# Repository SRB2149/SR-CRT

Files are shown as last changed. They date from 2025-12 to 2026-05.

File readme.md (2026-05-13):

# CRT HDMI Bridge

Live HDMI video on a vintage monochrome CRT, via a Raspberry Pi, an FPGA and a custom interface PCB.

A desktop PC outputs HDMI to a USB capture card on a Raspberry Pi Zero 2 W. The Pi downscales the feed to 296x256, dithers it to 1 bit per pixel using Atkinson dither, and streams it over SPI to an FPGA. The FPGA then drives the Amstrad GT65 CRT monitor at 50 Hz.

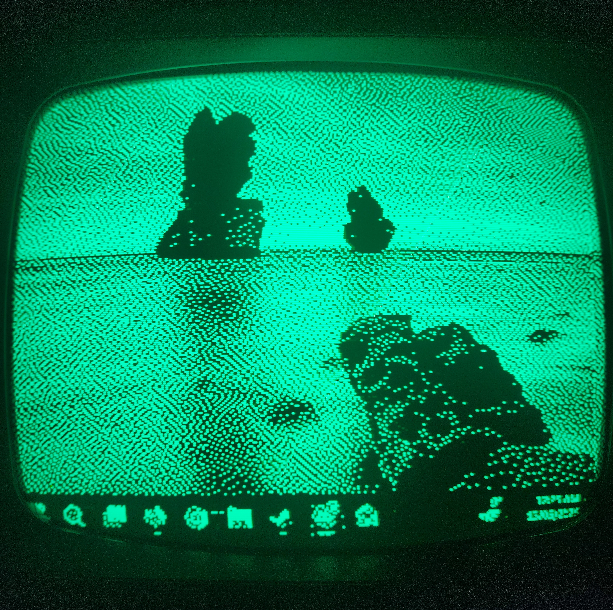
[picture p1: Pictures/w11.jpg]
Photo of a monochrome green CRT showing the windows 11 background.


## Hardware

- Raspberry Pi Zero 2 W
- UVC-compliant HDMI capture card (MS2130-based works well)
- Sipeed Tang Nano 9K (or any small FPGA with LVDS output and at least 16kiB Block SRAM)
- Custom interface PCB (The files are provided if you wish to have it fabricated - or if you would rather I still have some spare which can be bought. Enquire for more info)
- Amstrad GT65 monochrome CRT monitor
- 5V power supply (Or you can use the CRT's own 5V output)

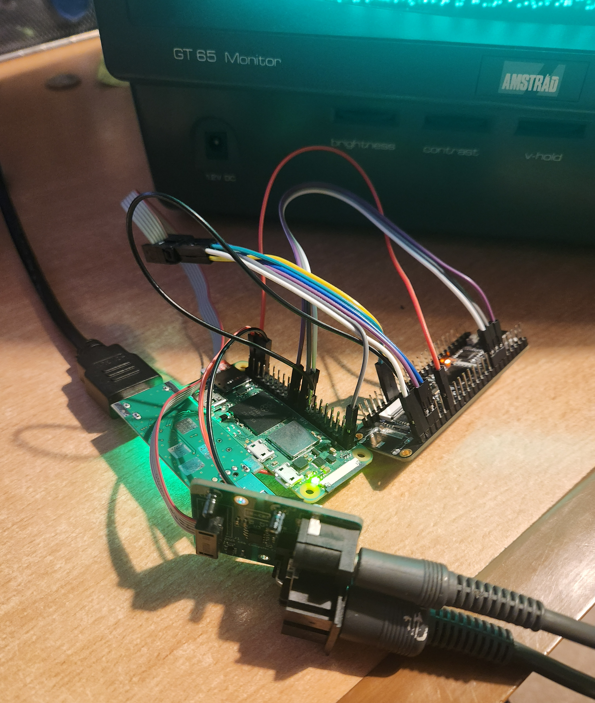
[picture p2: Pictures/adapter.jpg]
Photo of 4 PCBs connected with jumper wires connected to a CRT and a HDMI cable.


## How it works

```
PC --HDMI--> Capture Card --USB--> Pi --SPI--> FPGA --LVDS--> Interface PCB --Serial--> CRT
```

The Pi does the heavy lifting in software (capture, scale, dither). The FPGA does the time-critical CRT signal generation in hardware. SPI between them runs at 50 MHz and carries one 9472-byte framebuffer per CRT frame. The interface PCB acts as a level shifter as well as (depending on the setup) an electrical isolator. 
In theory the CRT could be directly driven using a level shifter from the FPGA, but you are on your own if you wish to attempt that.

In Windows 11 itself the monitor is set to 640x480 at 60 Hz.

The custom interface PCB once assembled
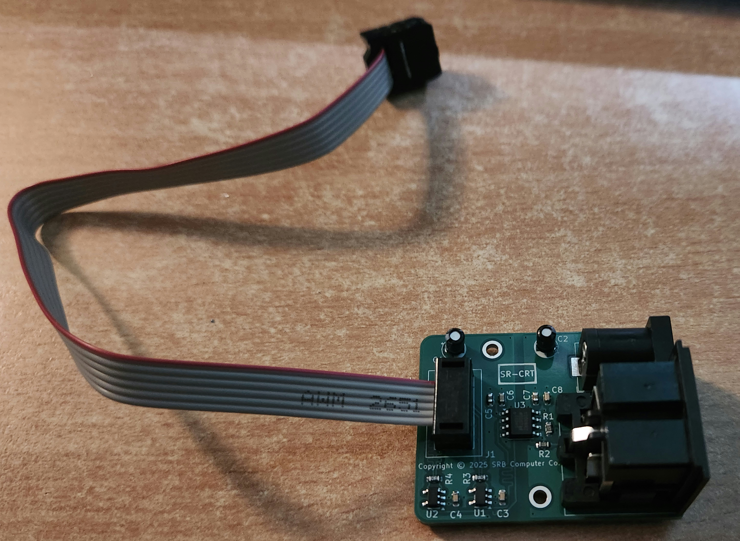
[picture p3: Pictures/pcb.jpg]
Photo of the interface PCB.


Here is the CRT showing the languages section of this repo!
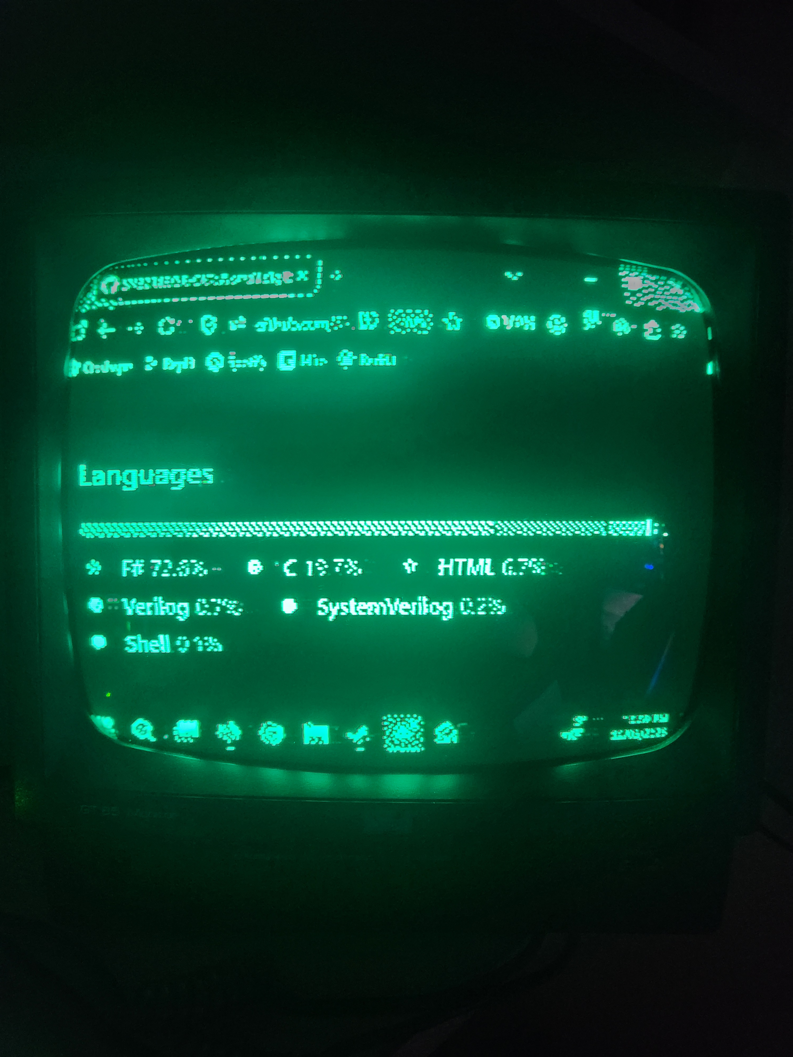
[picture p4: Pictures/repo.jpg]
Photo of the CRT displaying the languages section of this repository.


## Setup

For the Raspberry Pi side, see [INSTALL.txt](RPi/INSTALL.txt). The short version:

1. Flash Raspberry Pi OS Lite (64-bit) with WiFi and SSH preconfigured
2. `scp` the contents of `RPi/` to the Pi
3. Run `./setup_pi.sh` and reboot

For the FPGA side, open the project in your toolchain of choice and flash to your board. Pin assignments are in the top-level constraints file.
You can flash the [SPI_to_CRT.fs](FPGA/SPI_to_CRT/impl/pnr/SPI_to_CRT.fs) binary file directly if you have a GW1NR-LV9C (Tang Nano 9K) FPGA. Otherwise you will need to resynthesise etc.

## Acknowledgements

The Raspberry Pi software was written by Claude (Anthropic) under my supervision. The FPGA work and the rest is mine. For enquiries, contact contact@stanleybooth.uk.

## License

This project is licensed under the MIT License — see [LICENSE](LICENSE) for details.

## Gallery

Here are some more photos of the CRT in action. These photos do not capture the real feeling of the CRT particularly well. It looks much better in real life, especially when displaying videos or things that move as the ghosting leaves a very cool effect. The dithering also provides an incredible amount of information given the limited pixels. It really has to be seen in person to truly appreciate.

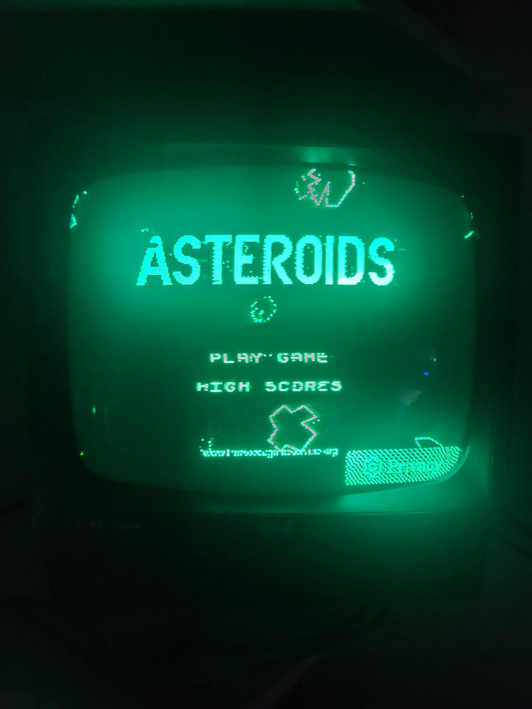
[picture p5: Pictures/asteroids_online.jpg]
Photo of the CRT with the game asteroids on it.

Asteroids online

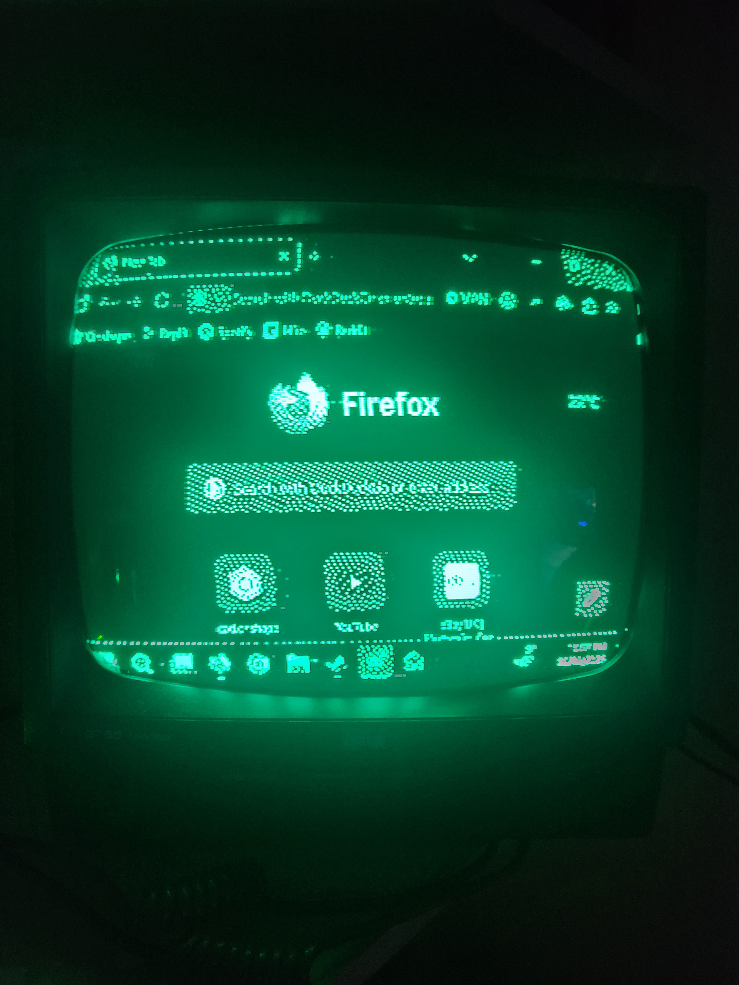
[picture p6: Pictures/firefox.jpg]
Photo of the CRT with a Firefox window open.

Firefox

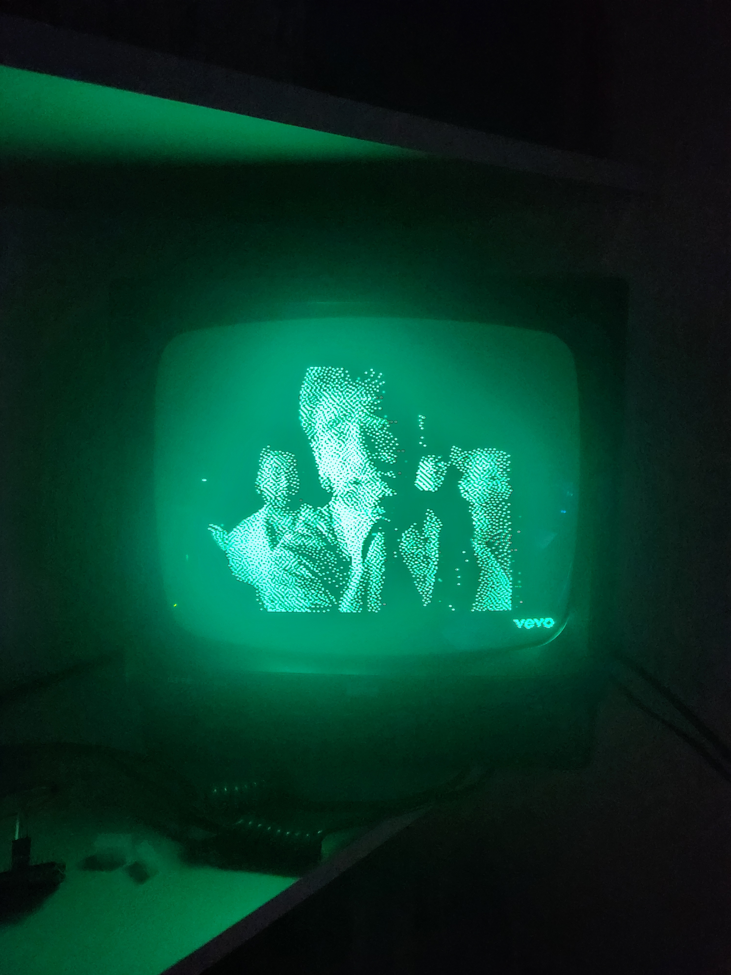
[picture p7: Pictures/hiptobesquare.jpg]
Photo of the CRT with a frame from the song "Hip to Be Square" by Huey Lewis and the News

A frame from the song "Hip to Be Square" by Huey Lewis and the News on youtube.

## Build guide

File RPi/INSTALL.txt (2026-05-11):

CRT HDMI Bridge - Raspberry Pi Setup Guide
==========================================

To preface:
The C code in this folder was written by Claude (Anthropic), not by me. 
Similarly this guide was written by Claude too, however I have read it myself
to check everything seems OK.
If you have any issues feel free to email contact@stanleybooth.uk

What you need
-------------
- Raspberry Pi Zero 2 W (other Pis should work but only the Zero 2 W is tested)
- A good 5V power supply (the official Pi PSU is fine; cheap phone chargers
  often aren't)
- A microSD card, 8GB or larger, ideally a name-brand A1-rated one
- A UVC-compliant HDMI capture card (anything that exposes YUYV at 640x480 over
  V4L2 will work; MS2130-based cards are cheap and good)
- The FPGA board with the matching SPI-to-CRT firmware

Operating system
----------------
Install Raspberry Pi OS Lite (64-bit) using Raspberry Pi Imager. In the
Imager's advanced options (gear icon), set:
  - hostname (something memorable like 'crtpi')
  - username and password
  - WiFi credentials (the Zero 2 W is 2.4 GHz only)
  - WiFi country (set this correctly or WiFi may refuse to associate)
  - enable SSH, ideally with public-key auth

Flash the card, put it in the Pi, power it on, and wait about 2 minutes for
first-boot to complete. Then SSH in from your laptop:

  ssh user@crtpi.local

Setup script
------------
Copy the project files to the Pi:

  scp setup_pi.sh build.sh v4l2_to_spi_atkinson.c user@crtpi.local:~/

SSH in and run the setup script:

  ssh user@crtpi.local
  chmod +x setup_pi.sh build.sh
  ./setup_pi.sh

This will install packages, enable SPI, set the spidev buffer size, configure
groups, build the binary, install the systemd service, and enable the
read-only root overlay. Reboot when it tells you to.

After reboot the program will start automatically and keep running. Power the
Pi by yanking the cable whenever you like - the SD card is mounted read-only
so it won't get corrupted.

Choosing the dither algorithm
-----------------------------
Two C files are provided:
  - v4l2_to_spi.c             - Bayer 8x8 ordered dither (cheap, fast)
  - v4l2_to_spi_atkinson.c    - Atkinson error-diffusion dither (much nicer)

The Atkinson dither looks significantly better in my opinion - it preserves
text and edges far better than Bayer and is what the setup script uses by
default. If you'd rather use Bayer, edit build.sh to point at v4l2_to_spi.c
instead.

Useful commands
---------------
After install:

  sudo systemctl status v4l2-to-spi      # check the program is running
  journalctl -u v4l2-to-spi -f           # watch the output (fps etc.)
  sudo systemctl restart v4l2-to-spi     # restart after changes
  sudo systemctl stop v4l2-to-spi        # stop temporarily

To edit the program you'll need to disable the read-only overlay first:

  sudo raspi-config
  # Performance Options -> Overlay FS -> No
  # Reboot

Then edit, rebuild with ./build.sh, restart the service, and re-enable
overlay when you're done.

Troubleshooting
---------------
"Can't connect to capture card" - run v4l2-ctl --list-devices to confirm
it's plugged in and the kernel sees it.

"SPI errors" - check /sys/module/spidev/parameters/bufsiz is 65536. If not,
the setup script's cmdline.txt edit didn't take effect.

"No image on CRT" - probe MOSI, SCLK, and CS with a logic analyzer. You
should see ~1.5 ms bursts at 60 Hz with CS held low for the duration.

"Under-voltage warnings" - get a better power supply. Check with:
  vcgencmd get_throttled
A return value of 0x0 means everything is fine.

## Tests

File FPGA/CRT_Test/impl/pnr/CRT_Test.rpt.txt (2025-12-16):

//Copyright (C)2014-2024 Gowin Semiconductor Corporation.
//All rights reserved.

1. PnR Messages

  <Report Title>: PnR Report
  <Design File>: C:\Users\stanr\Documents\SR-CRT\FPGA\CRT_Test\impl\gwsynthesis\CRT_Test.vg
  <Physical Constraints File>: C:\Users\stanr\Documents\SR-CRT\FPGA\CRT_Test\src\CRT_Test.cst
  <Timing Constraints File>: ---
  <Tool Version>: V1.9.10.03 Education (64-bit)
  <Part Number>: GW1NR-LV9QN88PC6/I5
  <Device>: GW1NR-9
  <Device Version>: C
  <Created Time>:Mon Dec 15 19:43:51 2025

2. PnR Details

  Running placement:
    Placement Phase 0: CPU time = 0h 0m 0.008s, Elapsed time = 0h 0m 0.008s
    Placement Phase 1: CPU time = 0h 0m 0.068s, Elapsed time = 0h 0m 0.067s
    Placement Phase 2: CPU time = 0h 0m 0.008s, Elapsed time = 0h 0m 0.009s
    Placement Phase 3: CPU time = 0h 0m 0.502s, Elapsed time = 0h 0m 0.503s
    Total Placement: CPU time = 0h 0m 0.586s, Elapsed time = 0h 0m 0.587s
 Running routing:
    Routing Phase 0: CPU time = 0h 0m 0.001s, Elapsed time = 0h 0m 0s
    Routing Phase 1: CPU time = 0h 0m 0.087s, Elapsed time = 0h 0m 0.088s
    Routing Phase 2: CPU time = 0h 0m 0.091s, Elapsed time = 0h 0m 0.091s
    Routing Phase 3: CPU time = 0h 0m 0s, Elapsed time = 0h 0m 0s
    Total Routing: CPU time = 0h 0m 0.179s, Elapsed time = 0h 0m 0.179s
 Generate output files:
    CPU time = 0h 0m 0.737s, Elapsed time = 0h 0m 0.736s

 Total Time and Memory Usage: CPU time = 0h 0m 2s, Elapsed time = 0h 0m 2s, Peak memory usage = 470MB

3. Resource Usage Summary

  --------------------------------------------------------------------------------
  Resources                   | Usage                               | Utilization
  --------------------------------------------------------------------------------
  Logic                       | 151/8640                            |  2%
    --LUT,ALU,ROM16           | 151(151 LUT, 0 ALU, 0 ROM16)        | -
    --SSRAM(RAM16)            | 0                                   | -
  Register                    | 52/6693                             |  <1%
    --Logic Register as Latch | 0/6480                              |  0%
    --Logic Register as FF    | 52/6480                             |  <1%
    --I/O Register as Latch   | 0/213                               |  0%
    --I/O Register as FF      | 0/213                               |  0%
  CLS                         | 86/4320                             |  2%
  I/O Port                    | 7/71                                |  10%
  I/O Buf                     | 5                                   | -
    --Input Buf               | 1                                   | -
    --Output Buf              | 4                                   | -
    --Inout Buf               | 0                                   | -
  BSRAM                       | 5/26                                | 20%
    --DPB                     | 5
  ================================================================================

4. I/O Bank Usage Summary

  --------------------------------------
  I/O Bank  | Usage       | Utilization 
  --------------------------------------
  bank 1   | 2/25        | 8%          
  bank 2   | 4/23        | 18%         
  bank 3   | 1/23        | 5%          
  ======================================

5. Clock Resource Usage Summary

  ------------------------------------------
  Clock Resource| Usage         | Utilization 
  ------------------------------------------
  PRIMARY       | 1/8           | 13%
  LW            | 1/8           | 13%
  GCLK_PIN      | 0/3           | 0%
  OSC           | 1/1           | 100%
  ==========================================

6. Global Clock Signals

  -------------------------------------------
  Signal         | Global Clock   | Location
  -------------------------------------------
  clk            | PRIMARY        |  TL BR BL
  N_RESET_d      | LW             |  -
  ===========================================

7. Pinout by Port Name

------------------------------------------------------------------------------------------------------------------------------------------------------------------------------------------------------------------
Port Name  | Diff Pair | Loc./Bank     | Constraint | Dir.  | Site     | IO Type    | Drive | Pull Mode | PCI Clamp | Hysteresis | Open Drain | Vref       | Single Resistor | Diff Resistor | BankVccio 
------------------------------------------------------------------------------------------------------------------------------------------------------------------------------------------------------------------
N_RESET    | -         | 4/3           | Y          | in    | IOL5[A]  | LVCMOS18   | NA    | UP        | ON        | NONE       | NA         | NA         | OFF             | NA            | 1.8       
PIXEL      | PIXEL_N   | 54,53/1       | Y          | out   | IOR15    | LVDS25     | 2.5   | NONE      | NA        | NA         | NA         | NA         | NA              | NA            | 2.5       
SYNC       | SYNC_N    | 31,32/2       | Y          | out   | IOB15    | LVDS25     | 2.5   | NONE      | NA        | NA         | NA         | NA         | NA              | NA            | 2.5       
pixel      | -         | 38/2          | Y          | out   | IOB31[B] | LVCMOS25   | 8     | UP        | NA        | NA         | OFF        | NA         | NA              | NA            | 2.5       
sync       | -         | 37/2          | Y          | out   | IOB31[A] | LVCMOS25   | 8     | UP        | NA        | NA         | OFF        | NA         | NA              | NA            | 2.5       
==================================================================================================================================================================================================================

8. All Package Pins

-------------------------------------------------------------------------------------------------------------------------------------------------------------------------------------
Loc./Bank| Signal   | Dir.  | Site     | IO Type  | Drive | Pull Mode | PCI Clamp | Hysteresis | Open Drain | Vref       | Single Resistor | Diff Resistor | Bank Vccio
-------------------------------------------------------------------------------------------------------------------------------------------------------------------------------------
3/3      | -        | in    | IOT2[A]  | LVCMOS18 | NA    | UP        | ON        | NONE       | NA         | NA         | NA              | NA            | 1.8  
88/3     | -        | in    | IOT5[A]  | LVCMOS18 | NA    | UP        | ON        | NONE       | NA         | NA         | NA              | NA            | 1.8  
87/3     | -        | in    | IOT6[B]  | LVCMOS18 | NA    | UP        | ON        | NONE       | NA         | NA         | NA              | NA            | 1.8  
86/3     | -        | in    | IOT8[A]  | LVCMOS18 | NA    | UP        | ON        | NONE       | NA         | NA         | NA              | NA            | 1.8  
85/3     | -        | in    | IOT8[B]  | LVCMOS18 | NA    | UP        | ON        | NONE       | NA         | NA         | NA              | NA            | 1.8  
84/3     | -        | in    | IOT10[A] | LVCMOS18 | NA    | UP        | ON        | NONE       | NA         | NA         | NA              | NA            | 1.8  
83/3     | -        | in    | IOT10[B] | LVCMOS18 | NA    | UP        | ON        | NONE       | NA         | NA         | NA              | NA            | 1.8  
82/3     | -        | in    | IOT11[A] | LVCMOS18 | NA    | UP        | ON        | NONE       | NA         | NA         | NA              | NA            | 1.8  
81/3     | -        | in    | IOT11[B] | LVCMOS18 | NA    | UP        | ON        | NONE       | NA         | NA         | NA              | NA            | 1.8  
80/3     | -        | in    | IOT12[A] | LVCMOS18 | NA    | UP        | ON        | NONE       | NA         | NA         | NA              | NA            | 1.8  
79/3     | -        | in    | IOT12[B] | LVCMOS18 | NA    | UP        | ON        | NONE       | NA         | NA         | NA              | NA            | 1.8  
77/1     | -        | in    | IOT37[A] | LVCMOS18 | NA    | UP        | ON        | NONE       | NA         | NA         | NA              | NA            | 2.5  
76/1     | -        | in    | IOT37[B] | LVCMOS18 | NA    | UP        | ON        | NONE       | NA         | NA         | NA              | NA            | 2.5  
75/1     | -        | in    | IOT38[A] | LVCMOS18 | NA    | UP        | ON        | NONE       | NA         | NA         | NA              | NA            | 2.5  
74/1     | -        | in    | IOT38[B] | LVCMOS18 | NA    | UP        | ON        | NONE       | NA         | NA         | NA              | NA            | 2.5  
73/1     | -        | in    | IOT39[A] | LVCMOS18 | NA    | UP        | ON        | NONE       | NA         | NA         | NA              | NA            | 2.5  
72/1     | -        | in    | IOT39[B] | LVCMOS18 | NA    | UP        | ON        | NONE       | NA         | NA         | NA              | NA            | 2.5  
71/1     | -        | in    | IOT41[A] | LVCMOS18 | NA    | UP        | ON        | NONE       | NA         | NA         | NA              | NA            | 2.5  
70/1     | -        | in    | IOT41[B] | LVCMOS18 | NA    | UP        | ON        | NONE       | NA         | NA         | NA              | NA            | 2.5  
69/1     | -        | in    | IOT42[A] | LVCMOS18 | NA    | UP        | ON        | NONE       | NA         | NA         | NA              | NA            | 2.5  
68/1     | -        | in    | IOT42[B] | LVCMOS18 | NA    | UP        | ON        | NONE       | NA         | NA         | NA              | NA            | 2.5  
-------------------------------------------------------------------------------------------------------------------------------------------------------------------------------------
17/2     | -        | in    | IOB2[A]  | LVCMOS18 | NA    | UP        | ON        | NONE       | NA         | NA         | NA              | NA            | 2.5  
18/2     | -        | in    | IOB2[B]  | LVCMOS18 | NA    | UP        | ON        | NONE       | NA         | NA         | NA              | NA            | 2.5  
19/2     | -        | in    | IOB4[A]  | LVCMOS18 | NA    | UP        | ON        | NONE       | NA         | NA         | NA              | NA            | 2.5  
20/2     | -        | in    | IOB4[B]  | LVCMOS18 | NA    | UP        | ON        | NONE       | NA         | NA         | NA              | NA            | 2.5  
25/2     | -        | in    | IOB8[A]  | LVCMOS18 | NA    | UP        | ON        | NONE       | NA         | NA         | NA              | NA            | 2.5  
26/2     | -        | in    | IOB8[B]  | LVCMOS18 | NA    | UP        | ON        | NONE       | NA         | NA         | NA              | NA            | 2.5  
27/2     | -        | in    | IOB11[A] | LVCMOS18 | NA    | UP        | ON        | NONE       | NA         | NA         | NA              | NA            | 2.5  
28/2     | -        | in    | IOB11[B] | LVCMOS18 | NA    | UP        | ON        | NONE       | NA         | NA         | NA              | NA            | 2.5  
29/2     | -        | in    | IOB13[A] | LVCMOS18 | NA    | UP        | ON        | NONE       | NA         | NA         | NA              | NA            | 2.5  
30/2     | -        | in    | IOB13[B] | LVCMOS18 | NA    | UP        | ON        | NONE       | NA         | NA         | NA              | NA            | 2.5  
31/2     | SYNC     | out   | IOB15[A] | LVDS25   | 2.5   | NONE      | NA        | NA         | NA         | NA         | NA              | NA            | 2.5  
32/2     | SYNC_N   | out   | IOB15[B] | LVDS25   | 2.5   | NONE      | NA        | NA         | NA         | NA         | NA              | NA            | 2.5  
33/2     | -        | in    | IOB23[A] | LVCMOS18 | NA    | UP        | ON        | NONE       | NA         | NA         | NA              | NA            | 2.5  
34/2     | -        | in    | IOB23[B] | LVCMOS18 | NA    | UP        | ON        | NONE       | NA         | NA         | NA              | NA            | 2.5  
35/2     | -        | in    | IOB29[A] | LVCMOS18 | NA    | UP        | ON        | NONE       | NA         | NA         | NA              | NA            | 2.5  
36/2     | -        | in    | IOB29[B] | LVCMOS18 | NA    | UP        | ON        | NONE       | NA         | NA         | NA              | NA            | 2.5  
37/2     | sync     | out   | IOB31[A] | LVCMOS25 | 8     | UP        | NA        | NA         | OFF        | NA         | NA              | NA            | 2.5  
38/2     | pixel    | out   | IOB31[B] | LVCMOS25 | 8     | UP        | NA        | NA         | OFF        | NA         | NA              | NA            | 2.5  
39/2     | -        | in    | IOB33[A] | LVCMOS18 | NA    | UP        | ON        | NONE       | NA         | NA         | NA              | NA            | 2.5  
40/2     | -        | in    | IOB33[B] | LVCMOS18 | NA    | UP        | ON        | NONE       | NA         | NA         | NA              | NA            | 2.5  
41/2     | -        | in    | IOB41[A] | LVCMOS18 | NA    | UP        | ON        | NONE       | NA         | NA         | NA              | NA            | 2.5  
42/2     | -        | in    | IOB41[B] | LVCMOS18 | NA    | UP        | ON        | NONE       | NA         | NA         | NA              | NA            | 2.5  
47/2     | -        | in    | IOB43[B] | LVCMOS18 | NA    | UP        | ON        | NONE       | NA         | NA         | NA              | NA            | 2.5  
-------------------------------------------------------------------------------------------------------------------------------------------------------------------------------------
4/3      | N_RESET  | in    | IOL5[A]  | LVCMOS18 | NA    | UP        | ON        | NONE       | NA         | NA         | OFF             | NA            | 1.8  
5/3      | -        | in    | IOL11[A] | LVCMOS18 | NA    | UP        | ON        | NONE       | NA         | NA         | NA              | NA            | 1.8  
6/3      | -        | in    | IOL11[B] | LVCMOS18 | NA    | UP        | ON        | NONE       | NA         | NA         | NA              | NA            | 1.8  
7/3      | -        | in    | IOL12[B] | LVCMOS18 | NA    | UP        | ON        | NONE       | NA         | NA         | NA              | NA            | 1.8  
8/3      | -        | out   | IOL13[A] | LVCMOS18 | 8     | UP        | NA        | NA         | OFF        | NA         | NA              | NA            | 1.8  
9/3      | -        | in    | IOL13[B] | LVCMOS18 | NA    | UP        | ON        | NONE       | NA         | NA         | NA              | NA            | 1.8  
10/3     | -        | in    | IOL15[A] | LVCMOS18 | NA    | UP        | ON        | NONE       | NA         | NA         | NA              | NA            | 1.8  
11/3     | -        | in    | IOL16[B] | LVCMOS18 | NA    | UP        | ON        | NONE       | NA         | NA         | NA              | NA            | 1.8  
13/3     | -        | in    | IOL21[B] | LVCMOS18 | NA    | UP        | ON        | NONE       | NA         | NA         | NA              | NA            | 1.8  
14/3     | -        | in    | IOL22[B] | LVCMOS18 | NA    | UP        | ON        | NONE       | NA         | NA         | NA              | NA            | 1.8  
15/3     | -        | in    | IOL25[B] | LVCMOS18 | NA    | UP        | ON        | NONE       | NA         | NA         | NA              | NA            | 1.8  
16/3     | -        | in    | IOL26[B] | LVCMOS18 | NA    | UP        | ON        | NONE       | NA         | NA         | NA              | NA            | 1.8  
-------------------------------------------------------------------------------------------------------------------------------------------------------------------------------------
63/1     | -        | in    | IOR5[A]  | LVCMOS18 | NA    | UP        | ON        | NONE       | NA         | NA         | NA              | NA            | 2.5  
62/1     | -        | in    | IOR11[A] | LVCMOS18 | NA    | UP        | ON        | NONE       | NA         | NA         | NA              | NA            | 2.5  
61/1     | -        | in    | IOR11[B] | LVCMOS18 | NA    | UP        | ON        | NONE       | NA         | NA         | NA              | NA            | 2.5  
60/1     | -        | in    | IOR12[A] | LVCMOS18 | NA    | UP        | ON        | NONE       | NA         | NA         | NA              | NA            | 2.5  
59/1     | -        | in    | IOR12[B] | LVCMOS18 | NA    | UP        | ON        | NONE       | NA         | NA         | NA              | NA            | 2.5  
57/1     | -        | in    | IOR13[A] | LVCMOS18 | NA    | UP        | ON        | NONE       | NA         | NA         | NA              | NA            | 2.5  
56/1     | -        | in    | IOR14[A] | LVCMOS18 | NA    | UP        | ON        | NONE       | NA         | NA         | NA              | NA            | 2.5  
55/1     | -        | in    | IOR14[B] | LVCMOS18 | NA    | UP        | ON        | NONE       | NA         | NA         | NA              | NA            | 2.5  
54/1     | PIXEL    | out   | IOR15[A] | LVDS25   | 2.5   | NONE      | NA        | NA         | NA         | NA         | NA              | NA            | 2.5  
53/1     | PIXEL_N  | out   | IOR15[B] | LVDS25   | 2.5   | NONE      | NA        | NA         | NA         | NA         | NA              | NA            | 2.5  
52/1     | -        | in    | IOR17[A] | LVCMOS18 | NA    | UP        | ON        | NONE       | NA         | NA         | NA              | NA            | 2.5  
51/1     | -        | in    | IOR17[B] | LVCMOS18 | NA    | UP        | ON        | NONE       | NA         | NA         | NA              | NA            | 2.5  
50/1     | -        | in    | IOR22[B] | LVCMOS18 | NA    | UP        | ON        | NONE       | NA         | NA         | NA              | NA            | 2.5  
49/1     | -        | in    | IOR24[A] | LVCMOS18 | NA    | UP        | ON        | NONE       | NA         | NA         | NA              | NA            | 2.5  
48/1     | -        | in    | IOR24[B] | LVCMOS18 | NA    | UP        | ON        | NONE       | NA         | NA         | NA              | NA            | 2.5  
-------------------------------------------------------------------------------------------------------------------------------------------------------------------------------------
=====================================================================================================================================================================================

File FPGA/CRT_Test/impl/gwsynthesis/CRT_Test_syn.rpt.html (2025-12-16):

- Synthesis Messages
- Synthesis Details
- Resource
  - Resource Usage Summary
  - Resource Utilization Summary
- Timing
  - Clock Summary
  - Max Frequency Summary
  - Detail Timing Paths Informations

# Synthesis Messages

Report Title | GowinSynthesis Report
Design File | C:\Users\stanr\Documents\SR-CRT\FPGA\Controller\amstrad_gt65_crt_controller.sv C:\Users\stanr\Documents\SR-CRT\FPGA\test.sv C:\Users\stanr\Documents\SR-CRT\FPGA\CRT_Test\src\gowin_osc\gowin_osc.v C:\Users\stanr\Documents\SR-CRT\FPGA\CRT_Test\src\gowin_dpb\crt_frame_buffer_dpbsram.v
GowinSynthesis Constraints File | ---
Tool Version | V1.9.10.03 Education (64-bit)
Part Number | GW1NR-LV9QN88PC6/I5
Device | GW1NR-9
Device Version | C
Created Time | Mon Dec 15 19:43:49 2025
Legal Announcement | Copyright (C)2014-2024 Gowin Semiconductor Corporation. ALL rights reserved.

# Synthesis Details

Top Level Module | CRT_Test

Synthesis Process

Running parser:
CPU time = 0h 0m 0.078s, Elapsed time = 0h 0m 0.075s, Peak memory usage = 470.621MB
Running netlist conversion:
CPU time = 0h 0m 0s, Elapsed time = 0h 0m 0s, Peak memory usage = 0MB
Running device independent optimization:
Optimizing Phase 0: CPU time = 0h 0m 0.015s, Elapsed time = 0h 0m 0.004s, Peak memory usage = 470.621MB
Optimizing Phase 1: CPU time = 0h 0m 0s, Elapsed time = 0h 0m 0.006s, Peak memory usage = 470.621MB
Optimizing Phase 2: CPU time = 0h 0m 0s, Elapsed time = 0h 0m 0.007s, Peak memory usage = 470.621MB
Running inference:
Inferring Phase 0: CPU time = 0h 0m 0.015s, Elapsed time = 0h 0m 0s, Peak memory usage = 470.621MB
Inferring Phase 1: CPU time = 0h 0m 0s, Elapsed time = 0h 0m 0s, Peak memory usage = 470.621MB
Inferring Phase 2: CPU time = 0h 0m 0s, Elapsed time = 0h 0m 0s, Peak memory usage = 470.621MB
Inferring Phase 3: CPU time = 0h 0m 0s, Elapsed time = 0h 0m 0s, Peak memory usage = 470.621MB
Running technical mapping:
Tech-Mapping Phase 0: CPU time = 0h 0m 0s, Elapsed time = 0h 0m 0.004s, Peak memory usage = 470.621MB
Tech-Mapping Phase 1: CPU time = 0h 0m 0s, Elapsed time = 0h 0m 0.001s, Peak memory usage = 470.621MB
Tech-Mapping Phase 2: CPU time = 0h 0m 0s, Elapsed time = 0h 0m 0s, Peak memory usage = 470.621MB
Tech-Mapping Phase 3: CPU time = 0h 0m 0.39s, Elapsed time = 0h 0m 0.393s, Peak memory usage = 470.621MB
Tech-Mapping Phase 4: CPU time = 0h 0m 0.015s, Elapsed time = 0h 0m 0.015s, Peak memory usage = 470.621MB
Generate output files:
CPU time = 0h 0m 0.015s, Elapsed time = 0h 0m 0.013s, Peak memory usage = 470.621MB
Total Time and Memory Usage | CPU time = 0h 0m 0.528s, Elapsed time = 0h 0m 0.518s, Peak memory usage = 470.621MB

# Resource

## Resource Usage Summary

Resource | Usage
I/O Port | 7
I/O Buf | 5
IBUF | 1
OBUF | 2
TLVDS_OBUF | 2
Register | 52
DFFE | 1
DFFPE | 1
DFFC | 14
DFFCE | 36
LUT | 134
LUT2 | 15
LUT3 | 36
LUT4 | 83
MUX | 8
MUX2 | 8
INV | 6
INV | 6
BSRAM | 5
DPB | 5
CLOCK | 1
OSC | 1

## Resource Utilization Summary

Resource | Usage | Utilization
Logic | 148(148 LUT, 0 ALU) / 8640 | 2%
Register | 52 / 6693 | <1%
--Register as Latch | 0 / 6693 | 0%
--Register as FF | 52 / 6693 | <1%
BSRAM | 5 / 26 | 20%

# Timing

## Clock Summary:

NO. | Clock Name | Type | Period | Frequency(MHz) | Rise | Fall | Source | Master | Object
1 | internal_clk0/osc_inst/OSCOUT.default_clk | Base | 16.000 | 62.5 | 0.000 | 8.000 | | | internal_clk0/osc_inst/OSCOUT

## Max Frequency Summary:

NO. | Clock Name | Constraint | Actual Fmax | Logic Level | Entity
1 | internal_clk0/osc_inst/OSCOUT.default_clk | 62.500(MHz) | 99.460(MHz) | 5 | TOP

## Detail Timing Paths Information

### Path 1

Path Summary:

Slack | 5.946
Data Arrival Time | 10.380
Data Required Time | 16.326
From | crt0/horizontal_counter_9_s0
To | crt0/vsync_s1
Launch Clk | internal_clk0/osc_inst/OSCOUT.default_clk[R]
Latch Clk | internal_clk0/osc_inst/OSCOUT.default_clk[R]

Data Arrival Path:

AT | DELAY | TYPE | RF | FANOUT | NODE
0.000 | 0.000 | | | | internal_clk0/osc_inst/OSCOUT.default_clk
0.000 | 0.000 | tCL | RR | 57 | internal_clk0/osc_inst/OSCOUT
0.726 | 0.726 | tNET | RR | 1 | crt0/horizontal_counter_9_s0/CLK
1.184 | 0.458 | tC2Q | RF | 9 | crt0/horizontal_counter_9_s0/Q
2.144 | 0.960 | tNET | FF | 1 | crt0/n384_s26/I1
3.243 | 1.099 | tINS | FF | 1 | crt0/n384_s26/F
4.203 | 0.960 | tNET | FF | 1 | crt0/n384_s20/I1
5.302 | 1.099 | tINS | FF | 1 | crt0/n384_s20/F
6.262 | 0.960 | tNET | FF | 1 | crt0/n384_s14/I1
7.361 | 1.099 | tINS | FF | 1 | crt0/n384_s14/F
8.321 | 0.960 | tNET | FF | 1 | crt0/n384_s12/I1
9.420 | 1.099 | tINS | FF | 1 | crt0/n384_s12/F
10.380 | 0.960 | tNET | FF | 1 | crt0/vsync_s1/D

Data Required Path:

AT | DELAY | TYPE | RF | FANOUT | NODE
16.000 | 0.000 | | | | internal_clk0/osc_inst/OSCOUT.default_clk
16.000 | 0.000 | tCL | RR | 57 | internal_clk0/osc_inst/OSCOUT
16.726 | 0.726 | tNET | RR | 1 | crt0/vsync_s1/CLK
16.326 | -0.400 | tSu | | 1 | crt0/vsync_s1

Path Statistics:

Clock Skew: | 0.000
Setup Relationship: | 16.000
Logic Level: | 5
Arrival Clock Path Delay: | cell: 0.000, 0.000%; route: 0.726, 100.000%
Arrival Data Path Delay: | cell: 4.396, 45.534%; route: 4.800, 49.719%; tC2Q: 0.458, 4.747%
Required Clock Path Delay: | cell: 0.000, 0.000%; route: 0.726, 100.000%

### Path 2

Path Summary:

Slack | 6.013
Data Arrival Time | 10.313
Data Required Time | 16.326
From | crt0/vertical_counter_4_s0
To | crt0/vertical_state_e_1_s6
Launch Clk | internal_clk0/osc_inst/OSCOUT.default_clk[R]
Latch Clk | internal_clk0/osc_inst/OSCOUT.default_clk[R]

Data Arrival Path:

AT | DELAY | TYPE | RF | FANOUT | NODE
0.000 | 0.000 | | | | internal_clk0/osc_inst/OSCOUT.default_clk
0.000 | 0.000 | tCL | RR | 57 | internal_clk0/osc_inst/OSCOUT
0.726 | 0.726 | tNET | RR | 1 | crt0/vertical_counter_4_s0/CLK
1.184 | 0.458 | tC2Q | RF | 9 | crt0/vertical_counter_4_s0/Q
2.144 | 0.960 | tNET | FF | 1 | crt0/vertical_state_e_2_s15/I1
3.243 | 1.099 | tINS | FF | 1 | crt0/vertical_state_e_2_s15/F
4.203 | 0.960 | tNET | FF | 1 | crt0/vertical_state_e_2_s11/I1
5.302 | 1.099 | tINS | FF | 2 | crt0/vertical_state_e_2_s11/F
6.262 | 0.960 | tNET | FF | 1 | crt0/n381_s26/I1
7.361 | 1.099 | tINS | FF | 1 | crt0/n381_s26/F
8.321 | 0.960 | tNET | FF | 1 | crt0/n381_s25/I0
9.353 | 1.032 | tINS | FF | 1 | crt0/n381_s25/F
10.313 | 0.960 | tNET | FF | 1 | crt0/vertical_state_e_1_s6/D

Data Required Path:

AT | DELAY | TYPE | RF | FANOUT | NODE
16.000 | 0.000 | | | | internal_clk0/osc_inst/OSCOUT.default_clk
16.000 | 0.000 | tCL | RR | 57 | internal_clk0/osc_inst/OSCOUT
16.726 | 0.726 | tNET | RR | 1 | crt0/vertical_state_e_1_s6/CLK
16.326 | -0.400 | tSu | | 1 | crt0/vertical_state_e_1_s6

Path Statistics:

Clock Skew: | 0.000
Setup Relationship: | 16.000
Logic Level: | 5
Arrival Clock Path Delay: | cell: 0.000, 0.000%; route: 0.726, 100.000%
Arrival Data Path Delay: | cell: 4.329, 45.153%; route: 4.800, 50.066%; tC2Q: 0.458, 4.781%
Required Clock Path Delay: | cell: 0.000, 0.000%; route: 0.726, 100.000%

### Path 3

Path Summary:

Slack | 6.223
Data Arrival Time | 10.103
Data Required Time | 16.326
From | crt0/vertical_counter_7_s0
To | crt0/vertical_state_e_0_s2
Launch Clk | internal_clk0/osc_inst/OSCOUT.default_clk[R]
Latch Clk | internal_clk0/osc_inst/OSCOUT.default_clk[R]

Data Arrival Path:

AT | DELAY | TYPE | RF | FANOUT | NODE
0.000 | 0.000 | | | | internal_clk0/osc_inst/OSCOUT.default_clk
0.000 | 0.000 | tCL | RR | 57 | internal_clk0/osc_inst/OSCOUT
0.726 | 0.726 | tNET | RR | 1 | crt0/vertical_counter_7_s0/CLK
1.184 | 0.458 | tC2Q | RF | 6 | crt0/vertical_counter_7_s0/Q
2.144 | 0.960 | tNET | FF | 1 | crt0/vertical_state_e_2_s13/I1
3.243 | 1.099 | tINS | FF | 3 | crt0/vertical_state_e_2_s13/F
4.203 | 0.960 | tNET | FF | 1 | crt0/vertical_state_e_2_s9/I2
5.025 | 0.822 | tINS | FF | 3 | crt0/vertical_state_e_2_s9/F
5.985 | 0.960 | tNET | FF | 1 | crt0/n382_s25/I1
7.084 | 1.099 | tINS | FF | 1 | crt0/n382_s25/F
8.044 | 0.960 | tNET | FF | 1 | crt0/n382_s24/I1
9.143 | 1.099 | tINS | FF | 1 | crt0/n382_s24/F
10.103 | 0.960 | tNET | FF | 1 | crt0/vertical_state_e_0_s2/D

Data Required Path:

AT | DELAY | TYPE | RF | FANOUT | NODE
16.000 | 0.000 | | | | internal_clk0/osc_inst/OSCOUT.default_clk
16.000 | 0.000 | tCL | RR | 57 | internal_clk0/osc_inst/OSCOUT
16.726 | 0.726 | tNET | RR | 1 | crt0/vertical_state_e_0_s2/CLK
16.326 | -0.400 | tSu | | 1 | crt0/vertical_state_e_0_s2

Path Statistics:

Clock Skew: | 0.000
Setup Relationship: | 16.000
Logic Level: | 5
Arrival Clock Path Delay: | cell: 0.000, 0.000%; route: 0.726, 100.000%
Arrival Data Path Delay: | cell: 4.119, 43.925%; route: 4.800, 51.187%; tC2Q: 0.458, 4.888%
Required Clock Path Delay: | cell: 0.000, 0.000%; route: 0.726, 100.000%

### Path 4

Path Summary:

Slack | 6.486
Data Arrival Time | 9.840
Data Required Time | 16.326
From | crt0/horizontal_counter_8_s0
To | crt0/horizontal_state_e_0_s2
Launch Clk | internal_clk0/osc_inst/OSCOUT.default_clk[R]
Latch Clk | internal_clk0/osc_inst/OSCOUT.default_clk[R]

Data Arrival Path:

AT | DELAY | TYPE | RF | FANOUT | NODE
0.000 | 0.000 | | | | internal_clk0/osc_inst/OSCOUT.default_clk
0.000 | 0.000 | tCL | RR | 57 | internal_clk0/osc_inst/OSCOUT
0.726 | 0.726 | tNET | RR | 1 | crt0/horizontal_counter_8_s0/CLK
1.184 | 0.458 | tC2Q | RF | 8 | crt0/horizontal_counter_8_s0/Q
2.144 | 0.960 | tNET | FF | 1 | crt0/horizontal_state_e_0_s8/I1
3.243 | 1.099 | tINS | FF | 1 | crt0/horizontal_state_e_0_s8/F
4.203 | 0.960 | tNET | FF | 1 | crt0/horizontal_state_e_0_s7/I0
5.235 | 1.032 | tINS | FF | 1 | crt0/horizontal_state_e_0_s7/F
6.195 | 0.960 | tNET | FF | 1 | crt0/horizontal_state_e_0_s5/I3
6.821 | 0.626 | tINS | FF | 3 | crt0/horizontal_state_e_0_s5/F
7.781 | 0.960 | tNET | FF | 1 | crt0/n585_s28/I1
8.880 | 1.099 | tINS | FF | 1 | crt0/n585_s28/F
9.840 | 0.960 | tNET | FF | 1 | crt0/horizontal_state_e_0_s2/D

Data Required Path:

AT | DELAY | TYPE | RF | FANOUT | NODE
16.000 | 0.000 | | | | internal_clk0/osc_inst/OSCOUT.default_clk
16.000 | 0.000 | tCL | RR | 57 | internal_clk0/osc_inst/OSCOUT
16.726 | 0.726 | tNET | RR | 1 | crt0/horizontal_state_e_0_s2/CLK
16.326 | -0.400 | tSu | | 1 | crt0/horizontal_state_e_0_s2

Path Statistics:

Clock Skew: | 0.000
Setup Relationship: | 16.000
Logic Level: | 5
Arrival Clock Path Delay: | cell: 0.000, 0.000%; route: 0.726, 100.000%
Arrival Data Path Delay: | cell: 3.856, 42.307%; route: 4.800, 52.664%; tC2Q: 0.458, 5.029%
Required Clock Path Delay: | cell: 0.000, 0.000%; route: 0.726, 100.000%

### Path 5

Path Summary:

Slack | 6.500
Data Arrival Time | 9.826
Data Required Time | 16.326
From | crt0/pixel_word_index_1_s0
To | crt0/pixel_word_index_11_s0
Launch Clk | internal_clk0/osc_inst/OSCOUT.default_clk[R]
Latch Clk | internal_clk0/osc_inst/OSCOUT.default_clk[R]

Data Arrival Path:

AT | DELAY | TYPE | RF | FANOUT | NODE
0.000 | 0.000 | | | | internal_clk0/osc_inst/OSCOUT.default_clk
0.000 | 0.000 | tCL | RR | 57 | internal_clk0/osc_inst/OSCOUT
0.726 | 0.726 | tNET | RR | 1 | crt0/pixel_word_index_1_s0/CLK
1.184 | 0.458 | tC2Q | RF | 9 | crt0/pixel_word_index_1_s0/Q
2.144 | 0.960 | tNET | FF | 1 | crt0/n722_s3/I1
3.243 | 1.099 | tINS | FF | 5 | crt0/n722_s3/F
4.203 | 0.960 | tNET | FF | 1 | crt0/n718_s4/I2
5.025 | 0.822 | tINS | FF | 5 | crt0/n718_s4/F
5.985 | 0.960 | tNET | FF | 1 | crt0/n715_s3/I2
6.807 | 0.822 | tINS | FF | 2 | crt0/n715_s3/F
7.767 | 0.960 | tNET | FF | 1 | crt0/n715_s2/I1
8.866 | 1.099 | tINS | FF | 1 | crt0/n715_s2/F
9.826 | 0.960 | tNET | FF | 1 | crt0/pixel_word_index_11_s0/D

Data Required Path:

AT | DELAY | TYPE | RF | FANOUT | NODE
16.000 | 0.000 | | | | internal_clk0/osc_inst/OSCOUT.default_clk
16.000 | 0.000 | tCL | RR | 57 | internal_clk0/osc_inst/OSCOUT
16.726 | 0.726 | tNET | RR | 1 | crt0/pixel_word_index_11_s0/CLK
16.326 | -0.400 | tSu | | 1 | crt0/pixel_word_index_11_s0

Path Statistics:

Clock Skew: | 0.000
Setup Relationship: | 16.000
Logic Level: | 5
Arrival Clock Path Delay: | cell: 0.000, 0.000%; route: 0.726, 100.000%
Arrival Data Path Delay: | cell: 3.842, 42.218%; route: 4.800, 52.746%; tC2Q: 0.458, 5.036%
Required Clock Path Delay: | cell: 0.000, 0.000%; route: 0.726, 100.000%

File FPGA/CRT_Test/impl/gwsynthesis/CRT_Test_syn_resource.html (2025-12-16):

# Hierarchy Module Resource

MODULE NAME | REG NUMBER | ALU NUMBER | LUT NUMBER | DSP NUMBER | BSRAM NUMBER | SSRAM NUMBER | ROM16 NUMBER
CRT_Test (C:/Users/stanr/Documents/SR-CRT/FPGA/test.sv) | - | - | 1 | - | - | - | -
|--crt0 (C:/Users/stanr/Documents/SR-CRT/FPGA/test.sv) | 51 | - | 139 | - | - | - | -
|--internal_clk0 (C:/Users/stanr/Documents/SR-CRT/FPGA/test.sv) | - | - | - | - | - | - | -
|--f_buf0 (C:/Users/stanr/Documents/SR-CRT/FPGA/test.sv) | 1 | - | 8 | - | 5 | - | -

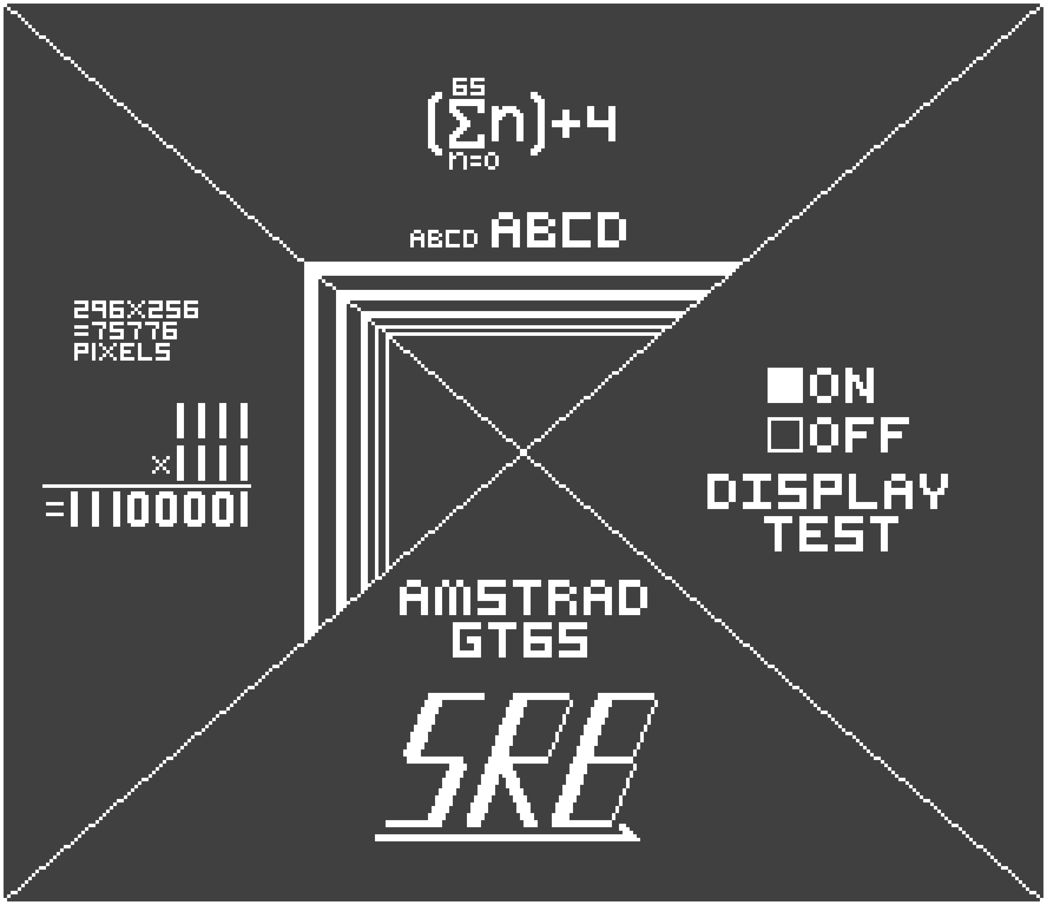
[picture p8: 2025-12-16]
FPGA/TestImages/GT65_296x256_Test.png

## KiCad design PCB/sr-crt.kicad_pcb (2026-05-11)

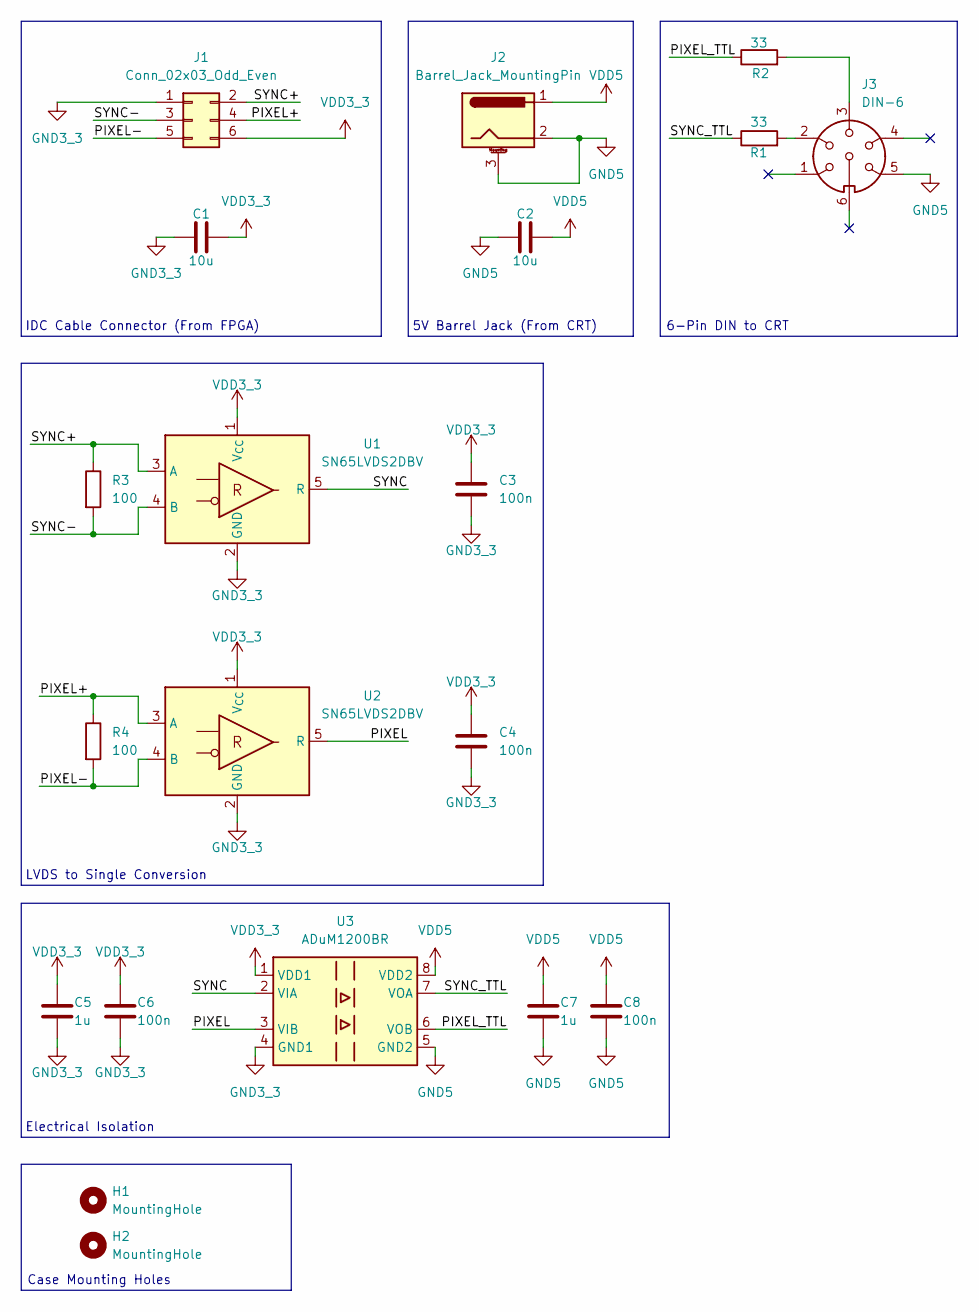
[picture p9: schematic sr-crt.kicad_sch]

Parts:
C1, C2: 10u; CP_Radial_D4.0mm_P2.00mm
C3, C4, C6, C8: 100n; C_0603_1608Metric
C5, C7: 1u; C_0603_1608Metric
H1, H2: MountingHole; MountingHole_2.2mm_M2_ISO7380_Pad_TopBottom
J1: Conn_02x03_Odd_Even; IDC-Header_2x03_P2.54mm_Vertical
J2: Barrel_Jack_MountingPin; BarrelJack_Horizontal
J3: DIN-6; 6_PIN_DIN
R1, R2: 33; R_0603_1608Metric
R3, R4: 100; R_0603_1608Metric
U1, U2: SN65LVDS2DBV; SOT-23-5
U3: ADuM1200BR; SOIC-8_3.9x4.9mm_P1.27mm

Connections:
/PIXEL: U2.5 (R), U3.3 (VIB)
/PIXEL+: J1.4, R4.1, U2.3 (A)
/PIXEL-: J1.5, R4.2, U2.4 (B)
/PIXEL_TTL: R2.1, U3.6 (VOB)
/SYNC: U1.5 (R), U3.2 (VIA)
/SYNC+: J1.2, R3.1, U1.3 (A)
/SYNC-: J1.3, R3.2, U1.4 (B)
/SYNC_TTL: R1.1, U3.7 (VOA)
GND3_3: C1.1, C3.2, C4.2, C5.2, C6.2, J1.1, U1.2 (GND), U2.2 (GND), U3.4 (GND1)
GND5: C2.1, C7.2, C8.2, J2.2, J2.3 (MountPin), J3.5, U3.5 (GND2)
unnamed: J3.2, R1.2
unnamed: J3.3, R2.2
VDD3_3: C1.2, C3.1, C4.1, C5.1, C6.1, J1.6, U1.1 (V_{CC}), U2.1 (V_{CC}), U3.1 (VDD1)
VDD5: C2.2, C7.1, C8.1, J2.1, U3.8 (VDD2)

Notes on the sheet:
6-Pin DIN to CRT
IDC Cable Connector (From FPGA)
5V Barrel Jack (From CRT)
LVDS to Single Conversion
Case Mounting Holes
Electrical Isolation

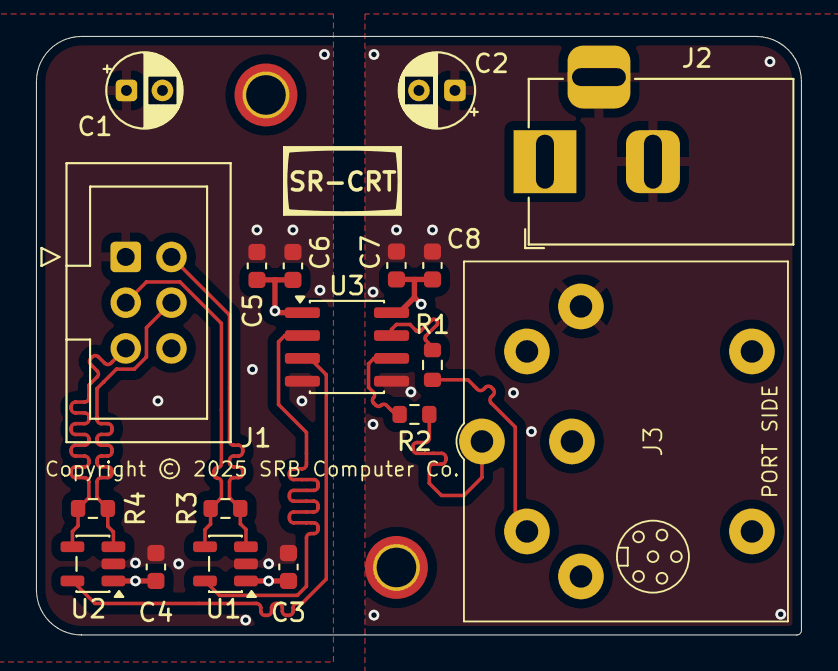
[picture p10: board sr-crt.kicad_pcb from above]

Board: 4 copper layers, 42.5 x 33.2 mm, 20 parts (0 on the bottom side), 14 nets.

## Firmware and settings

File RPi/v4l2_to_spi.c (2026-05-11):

/*
 * v4l2_to_spi.c — capture from a UVC HDMI capture card, downscale to
 * 320x240, dither to 1bpp, and stream to an FPGA over SPI.
 *
 * Designed for a Raspberry Pi Zero 2 W. Assumes the capture card can
 * deliver YUY2 (preferred) or MJPEG. This skeleton handles YUY2 directly;
 * MJPEG requires adding a decode step (see notes at bottom).
 *
 * Build:
 *   gcc -O3 -march=armv8-a -mtune=cortex-a53 -o v4l2_to_spi v4l2_to_spi.c
 *
 * Run (as root or with appropriate permissions on /dev/video0 and /dev/spidev0.0):
 *   ./v4l2_to_spi
 */

#include <errno.h>
#include <fcntl.h>
#include <stdint.h>
#include <stdio.h>
#include <stdlib.h>
#include <string.h>
#include <sys/ioctl.h>
#include <sys/mman.h>
#include <sys/time.h>
#include <unistd.h>
#include <linux/videodev2.h>
#include <linux/spi/spidev.h>

/* ------------------------------------------------------------------ */
/* Configuration                                                       */
/* ------------------------------------------------------------------ */

#define VIDEO_DEV    "/dev/video0"
#define SPI_DEV      "/dev/spidev0.0"

#define CAP_WIDTH    640
#define CAP_HEIGHT   480
#define OUT_WIDTH    296
#define OUT_HEIGHT   256
#define OUT_BYTES    (OUT_WIDTH * OUT_HEIGHT / 8)   /* 9472 bytes, 1bpp */

#define SPI_SPEED_HZ 50000000   /* 50 MHz — drop to 25 MHz if unstable */
#define SPI_BITS     8
#define SPI_MODE     SPI_MODE_0

#define NUM_BUFFERS  4

/* ------------------------------------------------------------------ */
/* Globals                                                             */
/* ------------------------------------------------------------------ */

struct buffer {
    void   *start;
    size_t  length;
};

static int             video_fd = -1;
static int             spi_fd   = -1;
static struct buffer   buffers[NUM_BUFFERS];
static uint8_t         gray_frame[CAP_WIDTH * CAP_HEIGHT];   /* full-res Y plane */
static uint8_t         scaled_frame[OUT_WIDTH * OUT_HEIGHT]; /* 320x240 grayscale */
static uint8_t         packed_frame[OUT_BYTES];              /* 1bpp output */

/* ------------------------------------------------------------------ */
/* Helpers                                                             */
/* ------------------------------------------------------------------ */

static int xioctl(int fd, unsigned long req, void *arg)
{
    int r;
    do { r = ioctl(fd, req, arg); } while (r == -1 && errno == EINTR);
    return r;
}

static void die(const char *msg)
{
    fprintf(stderr, "FATAL: %s: %s\n", msg, strerror(errno));
    exit(1);
}

/* ------------------------------------------------------------------ */
/* V4L2 setup                                                          */
/* ------------------------------------------------------------------ */

static void v4l2_open_and_configure(void)
{
    video_fd = open(VIDEO_DEV, O_RDWR | O_NONBLOCK);
    if (video_fd < 0) die("open video device");

    struct v4l2_capability cap;
    if (xioctl(video_fd, VIDIOC_QUERYCAP, &cap) < 0) die("VIDIOC_QUERYCAP");
    if (!(cap.capabilities & V4L2_CAP_VIDEO_CAPTURE))
        { fprintf(stderr, "device is not a video capture device\n"); exit(1); }

    struct v4l2_format fmt = {0};
    fmt.type                = V4L2_BUF_TYPE_VIDEO_CAPTURE;
    fmt.fmt.pix.width       = CAP_WIDTH;
    fmt.fmt.pix.height      = CAP_HEIGHT;
    fmt.fmt.pix.pixelformat = V4L2_PIX_FMT_YUYV;   /* YUY2 */
    fmt.fmt.pix.field       = V4L2_FIELD_NONE;
    if (xioctl(video_fd, VIDIOC_S_FMT, &fmt) < 0) die("VIDIOC_S_FMT");

    if (fmt.fmt.pix.pixelformat != V4L2_PIX_FMT_YUYV) {
        fprintf(stderr,
            "Driver did not accept YUYV. Got fourcc 0x%08x.\n"
            "If this is MJPEG, add a decode step (see end of file).\n",
            fmt.fmt.pix.pixelformat);
        exit(1);
    }
    if (fmt.fmt.pix.width != CAP_WIDTH || fmt.fmt.pix.height != CAP_HEIGHT) {
        fprintf(stderr, "Driver gave us %ux%u instead of %ux%u — adjust CAP_* and rebuild.\n",
                fmt.fmt.pix.width, fmt.fmt.pix.height, CAP_WIDTH, CAP_HEIGHT);
        exit(1);
    }

    /* Try to set 60 fps. 50 fps isn't offered for YUYV on this card,
     * so we capture at 60 and let the FPGA pull frames at its 50 Hz CRT
     * refresh rate. Causes mild judder on motion (1 dropped/repeated
     * frame every 5 refreshes) but is otherwise transparent. */
    struct v4l2_streamparm sp = {0};
    sp.type = V4L2_BUF_TYPE_VIDEO_CAPTURE;
    sp.parm.capture.timeperframe.numerator   = 1;
    sp.parm.capture.timeperframe.denominator = 60;
    xioctl(video_fd, VIDIOC_S_PARM, &sp);

    /* Request buffers */
    struct v4l2_requestbuffers req = {0};
    req.count  = NUM_BUFFERS;
    req.type   = V4L2_BUF_TYPE_VIDEO_CAPTURE;
    req.memory = V4L2_MEMORY_MMAP;
    if (xioctl(video_fd, VIDIOC_REQBUFS, &req) < 0) die("VIDIOC_REQBUFS");
    if (req.count < 2) { fprintf(stderr, "not enough buffers\n"); exit(1); }

    for (unsigned i = 0; i < req.count; i++) {
        struct v4l2_buffer buf = {0};
        buf.type   = V4L2_BUF_TYPE_VIDEO_CAPTURE;
        buf.memory = V4L2_MEMORY_MMAP;
        buf.index  = i;
        if (xioctl(video_fd, VIDIOC_QUERYBUF, &buf) < 0) die("VIDIOC_QUERYBUF");

        buffers[i].length = buf.length;
        buffers[i].start  = mmap(NULL, buf.length,
                                 PROT_READ | PROT_WRITE, MAP_SHARED,
                                 video_fd, buf.m.offset);
        if (buffers[i].start == MAP_FAILED) die("mmap");
    }

    /* Queue all buffers and start streaming */
    for (unsigned i = 0; i < req.count; i++) {
        struct v4l2_buffer buf = {0};
        buf.type   = V4L2_BUF_TYPE_VIDEO_CAPTURE;
        buf.memory = V4L2_MEMORY_MMAP;
        buf.index  = i;
        if (xioctl(video_fd, VIDIOC_QBUF, &buf) < 0) die("VIDIOC_QBUF (init)");
    }

    enum v4l2_buf_type t = V4L2_BUF_TYPE_VIDEO_CAPTURE;
    if (xioctl(video_fd, VIDIOC_STREAMON, &t) < 0) die("VIDIOC_STREAMON");
}

/* ------------------------------------------------------------------ */
/* SPI setup                                                           */
/* ------------------------------------------------------------------ */

static void spi_open_and_configure(void)
{
    spi_fd = open(SPI_DEV, O_RDWR);
    if (spi_fd < 0) die("open spi device");

    uint8_t mode = SPI_MODE;
    if (ioctl(spi_fd, SPI_IOC_WR_MODE, &mode) < 0) die("SPI_IOC_WR_MODE");

    uint8_t bits = SPI_BITS;
    if (ioctl(spi_fd, SPI_IOC_WR_BITS_PER_WORD, &bits) < 0) die("SPI bits/word");

    uint32_t speed = SPI_SPEED_HZ;
    if (ioctl(spi_fd, SPI_IOC_WR_MAX_SPEED_HZ, &speed) < 0) die("SPI speed");

    /* Increase the spidev buffer size limit if the kernel default (4096) is
     * smaller than our 9600-byte frame. On Raspberry Pi OS this is usually
     * already configured to 65536 via /sys/module/spidev/parameters/bufsiz,
     * but check with: cat /sys/module/spidev/parameters/bufsiz
     * If it's too small, add `spidev.bufsiz=65536` to /boot/cmdline.txt. */
}

/* ------------------------------------------------------------------ */
/* Image processing                                                    */
/* ------------------------------------------------------------------ */

/*
 * YUY2 layout:  Y0 U0 Y1 V0  Y2 U1 Y3 V1  ...
 * We only want luma — every even byte. Extract straight into gray_frame.
 */
static void yuy2_extract_luma(const uint8_t *yuy2)
{
    const uint8_t *src = yuy2;
    uint8_t *dst = gray_frame;
    const uint8_t *end = dst + (CAP_WIDTH * CAP_HEIGHT);
    while (dst < end) {
        /* unrolled 8 pixels at a time — compiler will vectorize this with NEON */
        dst[0] = src[0];  dst[1] = src[2];
        dst[2] = src[4];  dst[3] = src[6];
        dst[4] = src[8];  dst[5] = src[10];
        dst[6] = src[12]; dst[7] = src[14];
        src += 16;
        dst += 8;
    }
}

/*
 * Bilinear downscale from CAP_WIDTH x CAP_HEIGHT (640x480)
 * to OUT_WIDTH x OUT_HEIGHT (296x256).
 *
 * Uses 16.16 fixed-point arithmetic — no floats, fast on Cortex-A53.
 * Steps:
 *   step_x = 640/296 ≈ 2.162 source pixels per output pixel
 *   step_y = 480/256 ≈ 1.875 source pixels per output pixel
 * Each output pixel is the bilinear blend of the 4 surrounding
 * source pixels.
 */
static void downscale_bilinear(void)
{
    const uint32_t step_x = (CAP_WIDTH  << 16) / OUT_WIDTH;
    const uint32_t step_y = (CAP_HEIGHT << 16) / OUT_HEIGHT;

    uint32_t src_y_fp = 0;
    for (int y = 0; y < OUT_HEIGHT; y++) {
        const int      sy0 = src_y_fp >> 16;
        const int      sy1 = (sy0 + 1 < CAP_HEIGHT) ? sy0 + 1 : sy0;
        const uint32_t fy  = src_y_fp & 0xFFFF;
        const uint32_t ify = 0x10000 - fy;

        const uint8_t *r0  = &gray_frame[sy0 * CAP_WIDTH];
        const uint8_t *r1  = &gray_frame[sy1 * CAP_WIDTH];
        uint8_t       *out = &scaled_frame[y * OUT_WIDTH];

        uint32_t src_x_fp = 0;
        for (int x = 0; x < OUT_WIDTH; x++) {
            const int      sx0 = src_x_fp >> 16;
            const int      sx1 = (sx0 + 1 < CAP_WIDTH) ? sx0 + 1 : sx0;
            const uint32_t fx  = src_x_fp & 0xFFFF;
            const uint32_t ifx = 0x10000 - fx;

            uint32_t top    = (r0[sx0] * ifx + r0[sx1] * fx) >> 16;
            uint32_t bottom = (r1[sx0] * ifx + r1[sx1] * fx) >> 16;
            out[x] = (uint8_t)((top * ify + bottom * fy) >> 16);

            src_x_fp += step_x;
        }
        src_y_fp += step_y;
    }
}

/*
 * 8x8 Bayer ordered dither. Cheap, branchless, and looks good on a CRT.
 * The threshold matrix has values 0..63 mapped into 0..255.
 */
static const uint8_t bayer8[8][8] = {
    {  0, 32,  8, 40,  2, 34, 10, 42 },
    { 48, 16, 56, 24, 50, 18, 58, 26 },
    { 12, 44,  4, 36, 14, 46,  6, 38 },
    { 60, 28, 52, 20, 62, 30, 54, 22 },
    {  3, 35, 11, 43,  1, 33,  9, 41 },
    { 51, 19, 59, 27, 49, 17, 57, 25 },
    { 15, 47,  7, 39, 13, 45,  5, 37 },
    { 63, 31, 55, 23, 61, 29, 53, 21 }
};

/*
 * Threshold scaled_frame to 1bpp, packing 8 pixels per byte.
 * Bit ordering: pixel 0 is MSB of byte 0 (change if your FPGA expects LSB first).
 */
static void dither_and_pack(void)
{
    uint8_t *out = packed_frame;
    for (int y = 0; y < OUT_HEIGHT; y++) {
        const uint8_t *row = &scaled_frame[y * OUT_WIDTH];
        const uint8_t *brow = bayer8[y & 7];
        for (int x = 0; x < OUT_WIDTH; x += 8) {
            uint8_t b = 0;
            for (int k = 0; k < 8; k++) {
                /* Scale Bayer 0..63 into 0..255 by multiplying by 4, then
                 * compare to the pixel value. */
                uint8_t threshold = brow[(x + k) & 7] << 2;
                if (row[x + k] > threshold) b |= (uint8_t)(0x80 >> k);
            }
            *out++ = b;
        }
    }
}

/* ------------------------------------------------------------------ */
/* SPI write                                                           */
/* ------------------------------------------------------------------ */

static void spi_send_frame(void)
{
    /* For tx-only, a plain write() is the simplest path and uses DMA
     * automatically for transfers over ~96 bytes on Raspberry Pi. */
    ssize_t n = write(spi_fd, packed_frame, OUT_BYTES);
    if (n != OUT_BYTES) {
        fprintf(stderr, "SPI short write: %zd/%d (%s)\n",
                n, OUT_BYTES, strerror(errno));
    }
}

/* ------------------------------------------------------------------ */
/* Main loop                                                           */
/* ------------------------------------------------------------------ */

static double now_ms(void)
{
    struct timeval tv;
    gettimeofday(&tv, NULL);
    return tv.tv_sec * 1000.0 + tv.tv_usec / 1000.0;
}

int main(void)
{
    v4l2_open_and_configure();
    spi_open_and_configure();

    fprintf(stderr, "Streaming started.\n");

    double last_report = now_ms();
    int    frames      = 0;

    for (;;) {
        /* Wait for a frame */
        fd_set fds;
        FD_ZERO(&fds);
        FD_SET(video_fd, &fds);
        struct timeval tv = { .tv_sec = 2, .tv_usec = 0 };
        int r = select(video_fd + 1, &fds, NULL, NULL, &tv);
        if (r < 0 && errno != EINTR) die("select");
        if (r == 0) { fprintf(stderr, "select timeout\n"); continue; }

        /* Dequeue */
        struct v4l2_buffer buf = {0};
        buf.type   = V4L2_BUF_TYPE_VIDEO_CAPTURE;
        buf.memory = V4L2_MEMORY_MMAP;
        if (xioctl(video_fd, VIDIOC_DQBUF, &buf) < 0) {
            if (errno == EAGAIN) continue;
            die("VIDIOC_DQBUF");
        }

        /* Process */
        yuy2_extract_luma(buffers[buf.index].start);
        downscale_bilinear();
        dither_and_pack();
        spi_send_frame();

        /* Requeue */
        if (xioctl(video_fd, VIDIOC_QBUF, &buf) < 0) die("VIDIOC_QBUF");

        /* fps report once per second */
        frames++;
        double t = now_ms();
        if (t - last_report >= 1000.0) {
            fprintf(stderr, "%.1f fps\n", frames * 1000.0 / (t - last_report));
            frames = 0;
            last_report = t;
        }
    }

    /* (unreached) cleanup omitted */
    return 0;
}

/* ------------------------------------------------------------------ */
/* Notes                                                                */
/* ------------------------------------------------------------------ */
/*
 * If your card only offers MJPEG:
 *   Easiest path is libjpeg-turbo to decode each buffer to grayscale.
 *   In yuy2_extract_luma's place, call something like:
 *       tjDecompress2(handle, src, srcSize, gray_frame,
 *                     CAP_WIDTH, CAP_WIDTH, CAP_HEIGHT, TJPF_GRAY, 0);
 *   For best performance on the Zero 2 W, look at the V4L2 M2M JPEG
 *   decoder exposed by the VideoCore (/dev/video10..12) — it offloads
 *   decode to the GPU. That's a more involved integration; libjpeg-turbo
 *   on the CPU works for 640x480@30 in my estimation.
 *
 * Tuning:
 *   - If you see SPI errors, lower SPI_SPEED_HZ to 25_000_000.
 *   - If the dither pattern looks too "computery", swap dither_and_pack()
 *     for an Atkinson error-diffusion implementation.
 *   - If you want to flip bit ordering, change `0x80 >> k` to `1 << k`.
 *   - If your FPGA expects a frame-start signal, toggle a GPIO via
 *     /sys/class/gpio or libgpiod immediately before spi_send_frame().
 *
 * Permissions:
 *   Add your user to the `video` and `spi` groups, or run as root.
 */

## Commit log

2025-11-08 Started Schematic
    Added nearly everything except the 6-pin DIN connector
    [sr-crt.kicad_pcb, sr-crt.kicad_sch]
2025-11-08 Started PCB
    Also finished the schematic (as far as I am aware). Need to make DIN 6pin footprint once the connector arrives and I can measure it
    [sr-crt.kicad_pcb, sr-crt.kicad_sch]
2025-11-16 Added bits to silkscreen
    As above
    [sr-crt.kicad_pcb]
2025-11-23 Sent to manufacturing
    Specifically sr-crt-2.zip
    [sr-crt-B_Cu.gbr, sr-crt-B_Mask.gbr, sr-crt-B_Paste.gbr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]
2025-12-12 PCB Changes
    Note there is an error on the PCB at the moment. The middle pin on the DIN connector should be routed to the very top pin (on the footprint)
2025-12-16 Built CRT Controller
    [device.cfg]
2025-12-16 Updated PCB
    Fixed pin issues
    [sr-crt.kicad_pcb, sr-crt.kicad_sch]
2026-05-11 Moved PCB stuff to folder
    As above.
    [sr-crt.kicad_pcb, sr-crt.kicad_sch]
2026-05-11 Raspberry Pi Setup and Code
2026-05-11 Update amstrad_gt65_crt_controller.sv
    Added page switch signal to allow use of dual framebuffers.
2026-05-11 FPGA compilation things
    The FPGA should not need to be resynthesised at all as it is ready to program. Just use the SPI_to_CRT.fs file to flash program it and it should work just fine. As usual contact me if you need any he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
    [device.cfg]
2026-05-12 Removed Gerbers
    I think these are from the original PCB which had a few errors. Removed to reduce confusion.
    [sr-crt-B_Cu.gbr, sr-crt-B_Mask.gbr, sr-crt-B_Paste.gbr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]
2026-05-12 Cropped photos and added PCB photo.
    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

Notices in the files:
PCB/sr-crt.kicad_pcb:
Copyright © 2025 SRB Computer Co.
